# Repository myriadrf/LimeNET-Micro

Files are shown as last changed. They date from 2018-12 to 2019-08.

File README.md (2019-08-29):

# LimeNET-Micro

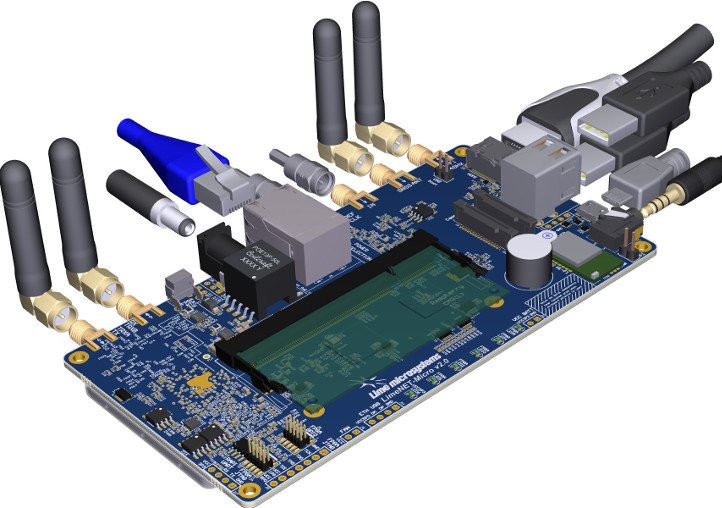
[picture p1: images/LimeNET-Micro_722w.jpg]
LimeNET-Micro board


The [LimeNET Micro](https://www.crowdsupply.com/lime-micro/limenet-micro) makes deploying wireless networks more accessible than ever before, by extending the LimeNET line of integrated hardware solutions via an ultra-low cost platform that is capable of supporting narrowband systems, such as GSM and IoT wireless standards, in a stand-alone configuration.

* **RF transceiver:** Lime Microsystems LMS7002M
* **FPGA Features** 
  * Intel Altera MAX 10 (10M16SAU169C8G)
  * 169-pin FBGA package
  * 16K LEs
  * 549 KB M9K memory
  * 2,368 KB user flash memory
  * 4 x fractional phase locked loops (PLLs)
  * 45 x 18x18-bit multipliers
  * 130 x general purpose input/output (GPIO)
  * Single supply voltage
  * Flash feature
  * FPGA configuration via JTAG
* **GNSS module:** u-blox NEO-M8Q-0-10
  * Supports BeiDou, Galileo, GLONASS, GPS / QZSS
  * Able to concurrently receive up to three GNSS
  * –167 dBm navigation sensitivity
* **EEPROM memory:** 2 x 128 KB for RF transceiver MCU firmware and data
* **Flash memory:** 1 x 4 MB flash memory for data
* **General user inputs/outputs:**
  * 5 x dual color (red + green) LED
  * 8 x FPGA GPIO pinheader (3.3 V)
  * 4 x FPGA switches
  * 1 x buzzer
* **Connectivity:**
  * 2 x coaxial RF (SMA) connectors (each can be switched between high and low frequency bands)
  * SMA connector for external clock source in
  * SMA connector for clock source out
  * SMA connector for GNSS antenna
  * Raspberry Pi Touch Screen Display Connector (ribbon cable)
  * Raspberry Pi Camera (ribbon cable)
  * HDMI connector
  * 2 x USB 2.0 ports
  * 3.5 mm audio out (Raspberry Pi Compute Module)
  * FPGA GPIO headers
  * FPGA JTAG connector
  * RJ45 connector for Ethernet and IEEE 802.3 active Power-over-Ethernet (PoE)
  * DDR2 SODIMM connector - only usable for Raspberry Pi Compute Module 3 (or Lite)
  * MicroSD slot for RPi Compute Module storage
  * Barrel connector for 5 V DC power
  * Micro-USB for USB boot of Compute Module
* **Clock system:**
  * 30.72 MHz OCXO: Rakon U7475LF
  * GPS disciplined for high frequency accuracy and stability
  * External clock input via SMA connector
  * Clock output via SMA connector
* **Board dimensions:** 125 mm x 65 mm

## Contents

The directory structure is as follows:

      hardware/<version>/
          Libraries/             - Component Libraries
          OutputJobs/            - Output jobs
          PCB/                   - PCB design
          Project Outputs/       - BOM, rule check reports, Gerbers, pick & place files, PDFs
          Schematics/            - Schematic diagrams

## Licensing

The hardware designs are licensed under a Creative Commons Attribution 3.0 Unported licence.

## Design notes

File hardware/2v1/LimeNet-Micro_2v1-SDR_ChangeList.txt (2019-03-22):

Changes:

LimeNet-Micro_2v1-SDR(_DB)_DFMr0:
 - Initial version

LimeNet-Micro_2v1-SDR(_DB)_DFMr1:
 - R77 changed from 10k to 22R (made same as ex. R135);
 - R114 made NF;
 - J26 made FIT;
 - New schematic and BOM (revision r1) generated.
 
LimeNet-Micro_2v1-SDR(_DB)_DFMr2:
 - R107 changed from 10k to 22R (made same as ex. R135);
 - New schematic and BOM (revision r2) generated.

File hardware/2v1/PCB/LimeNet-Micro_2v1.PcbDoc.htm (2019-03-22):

Reporting Options

# File in Previous Format

Date | : | 2019-02-14
Time | : | 10:52:01
Filename | : | d:\Lime\LimePCBs\LimeNET-Micro_2v1\History\SDR_FOR_CROWD\LimeNET-Micro_2v1-SDR_r01\PCB\LimeNet-Micro_2v1.PcbDoc

Version | Warning

This file was generated by an earlier version of the software

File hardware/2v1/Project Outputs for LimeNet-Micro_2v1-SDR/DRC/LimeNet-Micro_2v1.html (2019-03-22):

Altium

# Design Rule Verification Report

Date: | | 2019-01-22
Time: | | 12:07:39
Elapsed Time: | | 00:00:58
Filename: | | d:\Lime\LimePCBs\LimeNET-Micro_2v1\Altium Designer design files\PCB\LimeNet-Micro_2v1.PcbDoc

Warnings: | | 0
Rule Violations: | | 0

## Summary

Warnings | Count
Total | 0

Rule Violations | Count
Clearance Constraint (Gap=0.1mm) (All),(All) | 0
Short-Circuit Constraint (Allowed=No) (All),(All) | 0
Un-Routed Net Constraint ( (All) ) | 0
Modified Polygon (Allow modified: No), (Allow shelved: No) | 0
Width Constraint (Min=0.1mm) (Max=7mm) (Preferred=0.2mm) (All) | 0
Width Constraint (Min=0.1mm) (Max=5mm) (Preferred=0.2mm) (All) | 0
Routing Layers(All) | 0
Routing Via (MinHoleWidth=0.2mm) (MaxHoleWidth=4.5mm) (PreferredHoleWidth=0.2mm) (MinWidth=0.31mm) (MaxWidth=5mm) (PreferedWidth=0.4mm) (All) | 0
Differential Pairs Uncoupled Length using the Gap Constraints (Min=0.1mm) (Max=0.3mm) (Prefered=0.14mm) and Width Constraints (Min=0.2mm) (Max=0.2mm) (Prefered=0.2mm) (InNetClass('RAPI_HDMI')) | 0
Differential Pairs Uncoupled Length using the Gap Constraints (Min=0.1mm) (Max=0.3mm) (Prefered=0.1mm) and Width Constraints (Min=0.1mm) (Max=0.5mm) (Prefered=0.2mm) (All) | 0
Differential Pairs Uncoupled Length using the Gap Constraints (Min=0.1mm) (Max=0.3mm) (Prefered=0.14mm) and Width Constraints (Min=0.1mm) (Max=0.3mm) (Prefered=0.2mm) (InNetClass('TX_RF')) | 0
Differential Pairs Uncoupled Length using the Gap Constraints (Min=0.1mm) (Max=0.3mm) (Prefered=0.14mm) and Width Constraints (Min=0.1mm) (Max=0.3mm) (Prefered=0.2mm) (InNetClass('RX_RF')) | 0
Power Plane Connect Rule(Relief Connect )(Expansion=0.508mm) (Conductor Width=0.254mm) (Air Gap=0.254mm) (Entries=4) (All) | 0
Hole Size Constraint (Min=0.2mm) (Max=10mm) (All) | 0
Pads and Vias to follow the Drill pairs settings | 0
Hole To Hole Clearance (Gap=0.15mm) (All),(All) | 0
Minimum Solder Mask Sliver (Gap=0.099mm) (All),(All) | 0
Net Antennae (Tolerance=0mm) (All) | 0
Matched Lengths(Tolerance=1mm) (InNetClass('LMS_PORT1')) | 0
Matched Lengths(Tolerance=10mm) (InNetClass('LMS_PORT2')) | 0
Matched Lengths(Tolerance=1.6mm) (InNetClass('RAPI_SPI0')) | 0
Matched Lengths(Tolerance=1.6mm) (InNetClass('RAPI_SDX')) | 0
Matched Lengths(Tolerance=1.6mm) (InNetClass('RAPI_SPI1')) | 0
Matched Lengths(Tolerance=1.6mm) (InNetClass('FT_FIFO')) | 0
Component Clearance Constraint ( Horizontal Gap = -1mm, Vertical Gap = Infinite ) (InComponent('R171') or InComponent('R162') or InComponent('R174')),(InComponent('R171') or InComponent('R162') or InComponent('R174')) | 0
Component Clearance Constraint ( Horizontal Gap = -1mm, Vertical Gap = Infinite ) (InComponent('IC2')),(InComponent('IC3')) | 0
Component Clearance Constraint ( Horizontal Gap = -1mm, Vertical Gap = Infinite ) (InComponent('IC16')),(InComponent('IC18')) | 0
Component Clearance Constraint ( Horizontal Gap = -1mm, Vertical Gap = Infinite ) (HasFootprint('RFI_SHIELD_BMI-S-230-F-R')),(All) | 0
Component Clearance Constraint ( Horizontal Gap = 0.01mm, Vertical Gap = 0.254mm ) (All),(All) | 0
Component Clearance Constraint ( Horizontal Gap = -1mm, Vertical Gap = Infinite ) (InComponent('IC21')),(InComponent('IC20')) | 0
Component Clearance Constraint ( Horizontal Gap = -1mm, Vertical Gap = Infinite ) (InComponent('J27')),(InComponent('J28')) | 0
Component Clearance Constraint ( Horizontal Gap = -1mm, Vertical Gap = Infinite ) (HasFootprint('SW_4WAY_SMD_1P27_v2')),(All) | 0
Component Clearance Constraint ( Horizontal Gap = -1mm, Vertical Gap = Infinite ) (InComponent('IC12')),(InComponent('IC14')) | 0
Height Constraint (Min=0mm) (Max=25.4mm) (Prefered=12.7mm) (All) | 0
Total | 0

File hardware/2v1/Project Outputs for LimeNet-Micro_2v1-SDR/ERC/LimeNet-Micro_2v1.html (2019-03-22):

Altium

# Electrical Rule Check Report

Date: | | 2019-01-22
Time: | | 12:08:42
Filename: | | d:\Lime\LimePCBs\LimeNET-Micro_2v1\Altium Designer design files\Project Outputs for LimeNet-Micro_2v1\ERC\LimeNet-Micro_2v1.html

Class | Document | Message
Warning | LimeNet-Micro_2v1.PcbDoc | Component BR1 at 51.775mm,80.7mm: Can't perform revision status validation: Failed to connect to vault.
Warning | 15_PowerSupply.SchDoc | GND contains IO Pin and Output Pin objects (Pin IC12-F4,Pin IC46-PAD,Pin IC45-PAD,Pin IC40-PAD,Pin IC39-PAD)
Warning | 15_PowerSupply.SchDoc | GND contains IO Pin and Power Pin objects (Pin LED6-3,Pin IC16-4,Pin IC2-4,Pin IC37-5,Pin IC12-F4,Pin IC16-PAD,Pin IC2-PAD)
Warning | 10_USB_Ethernet.SchDoc | Net ETH_CLK24_EN has no driving source (Pin IC24-44,Pin R92-2,Pin R95-1)
Warning | 10_USB_Ethernet.SchDoc | Net ETH_USB_VBUS has no driving source (Pin IC24-11,Pin R80-2)
Warning | 13_Raspberry_Misc.SchDoc | Net EXT_USB_CTRL has no driving source (Pin IC29-10,Pin IC31-10,Pin J18-1,Pin R143-1,Pin R145-1)
Warning | 14_Clocks.SchDoc | Net FPGA_SPI_DAC_SS_R has no driving source (Pin IC35-5,Pin IC37-1,Pin R196-1)
Warning | 14_Clocks.SchDoc | Net FPGA_SPI_MOSI_R has no driving source (Pin IC35-7,Pin IC37-3,Pin R198-1)
Warning | 14_Clocks.SchDoc | Net FPGA_SPI_SCLK_R has no driving source (Pin IC35-6,Pin IC37-2,Pin R197-1)
Warning | 15_PowerSupply.SchDoc | Net GND contains multiple Output Pins (Pin IC46-PAD,Pin IC45-PAD,Pin IC40-PAD,Pin IC39-PAD)
Warning | 05_LMS7002M_Misc.SchDoc | Net LMS_I2C_SCL has no driving source (Pin IC1-C27,Pin IC2-6,Pin IC3-6,Pin R13-2)
Warning | 10_USB_Ethernet.SchDoc | Net NetC167_2 has no driving source (Pin C167-2,Pin IC24-61,Pin R86-1,Pin XT1-1)
Warning | 14_Clocks.SchDoc | Net NetC259_2 has no driving source (Pin C259-2,Pin XO4-7)
Warning | 15_PowerSupply.SchDoc | Net NetC312_2 has no driving source (Pin C312-2,Pin FR50-2,Pin IC41-5,Pin IC41-8)
Warning | 15_PowerSupply.SchDoc | Net NetC314_2 has no driving source (Pin C314-2,Pin FR51-2,Pin IC42-5,Pin IC42-8)
Warning | 15_PowerSupply.SchDoc | Net NetC316_1 has no driving source (Pin C316-1,Pin IC39-2,Pin R221-1,Pin R225-2)
Warning | 15_PowerSupply.SchDoc | Net NetC317_1 has no driving source (Pin C317-1,Pin IC40-2,Pin R222-1,Pin R226-2)
Warning | 15_PowerSupply.SchDoc | Net NetC318_2 has no driving source (Pin C318-2,Pin FR52-2,Pin IC43-5,Pin IC43-8)
Warning | 15_PowerSupply.SchDoc | Net NetC320_2 has no driving source (Pin C320-2,Pin FR53-2,Pin IC44-5,Pin IC44-8)
Warning | 15_PowerSupply.SchDoc | Net NetC327_1 has no driving source (Pin C327-1,Pin IC45-2,Pin R233-1,Pin R236-2)
Warning | 15_PowerSupply.SchDoc | Net NetC328_1 has no driving source (Pin C328-1,Pin IC46-2,Pin R234-1,Pin R237-2)
Warning | 08_FPGA.SchDoc | Net NetIC12_E7 has no driving source (Pin IC12-E7,Pin R40-2)
Warning | 10_USB_Ethernet.SchDoc | Net NetIC24_50 has no driving source (Pin IC24-50,Pin R94-1)
Warning | 10_USB_Ethernet.SchDoc | Net NetIC24_63 has no driving source (Pin IC24-63,Pin R93-1)
Warning | 10_USB_Ethernet.SchDoc | Net NetIC26_5 has no driving source (Pin IC26-5,Pin R100-1,Pin R101-1)
Warning | 13_Raspberry_Misc.SchDoc | Net NetIC28_10 has no driving source (Pin IC28-10,Pin R138-2,Pin VT5-D)
Warning | 13_Raspberry_Misc.SchDoc | Net NetIC30_9 has no driving source (Pin IC30-9,Pin R144-2)
Warning | 13_Raspberry_Misc.SchDoc | Net NetIC30_23 has no driving source (Pin IC30-23,Pin R147-2,Pin R148-2)
Warning | 13_Raspberry_Misc.SchDoc | Net NetIC30_25 has no driving source (Pin IC30-25,Pin R146-2,Pin R148-1,Pin R149-2)
Warning | 13_Raspberry_Misc.SchDoc | Net NetIC33_5 has no driving source (Pin IC33-5,Pin R160-1)
Warning | 15_PowerSupply.SchDoc | Net NetIC38_12 has no driving source (Pin IC38-12,Pin R209-2)
Warning | 15_PowerSupply.SchDoc | Net NetIC45_1 has no driving source (Pin IC45-1,Pin R229-2)
Warning | 15_PowerSupply.SchDoc | Net NetIC46_1 has no driving source (Pin IC46-1,Pin R230-2)
Warning | 15_PowerSupply.SchDoc | Net POE_CS has no driving source (Pin C307-1,Pin IC38-3,Pin R217-1)
Warning | 15_PowerSupply.SchDoc | Net POE_CTL has no driving source (Pin AT1-4,Pin C304-1,Pin IC38-1,Pin R213-2)
Warning | 13_Raspberry_Misc.SchDoc | Net RAPI_PWM0 has no driving source (Pin IC32-1,Pin J13-70)
Warning | 13_Raspberry_Misc.SchDoc | Net RAPI_PWM1 has no driving source (Pin IC32-3,Pin J13-72)
Warning | 12_Raspbbery CM3.SchDoc | Net RAPI_SD1_CLK has no driving source (Pin IC30-6,Pin R112-2)
Warning | 13_Raspberry_Misc.SchDoc | Net RAPI_SD1_CMD has no driving source (Pin IC30-7,Pin J13-54)
Warning | 14_Clocks.SchDoc | Net TCXO_DAC_VREF has no driving source (Pin C281-2,Pin C282-1,Pin IC35-2,Pin R185-1,Pin R186-1,Pin R187-1)
Warning | 15_PowerSupply.SchDoc | Net VCC5P0 has no driving source (Pin C175-2,Pin C177-1,Pin C231-2,Pin C233-1,Pin C308-2,Pin C310-2,Pin C322-2,Pin C323-2,Pin FR50-1,Pin FR52-1,Pin IC26-1,Pin IC26-3,Pin IC33-1,Pin IC33-3,Pin IC39-7,Pin IC40-7,Pin IC45-7,Pin IC46-7,Pin J3-7,Pin J26-2,Pin J27-2,Pin J27-4,Pin J27-6,Pin R33-1,Pin R61-1,Pin R98-2,Pin R99-1,Pin R103-2,Pin R120-2,Pin R158-2,Pin R159-1,Pin VD4-K)
Warning | 14_Clocks.SchDoc | Net XO_VC has no driving source (Pin R180-1,Pin R184-2,Pin XO1-1,Pin XO2-1,Pin XO3-1,Pin XO4-1)

Back to top

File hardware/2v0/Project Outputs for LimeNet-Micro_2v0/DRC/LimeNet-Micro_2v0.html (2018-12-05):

Altium

# Design Rule Verification Report

Date: | | 2018-11-13
Time: | | 16:06:43
Elapsed Time: | | 00:00:59
Filename: | | d:\Lime\LimePCBs\LimeNET-Micro_2v0\Altium Designer design files\PCB\LimeNet-Micro_2v0.PcbDoc

Warnings: | | 0
Rule Violations: | | 0

## Summary

Warnings | Count
Total | 0

Rule Violations | Count
Clearance Constraint (Gap=0.1mm) (All),(All) | 0
Short-Circuit Constraint (Allowed=No) (All),(All) | 0
Un-Routed Net Constraint ( (All) ) | 0
Modified Polygon (Allow modified: No), (Allow shelved: No) | 0
Width Constraint (Min=0.1mm) (Max=7mm) (Preferred=0.2mm) (All) | 0
Width Constraint (Min=0.1mm) (Max=5mm) (Preferred=0.2mm) (All) | 0
Routing Layers(All) | 0
Routing Via (MinHoleWidth=0.2mm) (MaxHoleWidth=4.5mm) (PreferredHoleWidth=0.2mm) (MinWidth=0.31mm) (MaxWidth=5mm) (PreferedWidth=0.4mm) (All) | 0
Differential Pairs Uncoupled Length using the Gap Constraints (Min=0.1mm) (Max=0.3mm) (Prefered=0.14mm) and Width Constraints (Min=0.2mm) (Max=0.2mm) (Prefered=0.2mm) (InNetClass('RAPI_HDMI')) | 0
Differential Pairs Uncoupled Length using the Gap Constraints (Min=0.1mm) (Max=0.3mm) (Prefered=0.1mm) and Width Constraints (Min=0.1mm) (Max=0.5mm) (Prefered=0.2mm) (All) | 0
Differential Pairs Uncoupled Length using the Gap Constraints (Min=0.1mm) (Max=0.3mm) (Prefered=0.14mm) and Width Constraints (Min=0.1mm) (Max=0.3mm) (Prefered=0.2mm) (InNetClass('TX_RF')) | 0
Differential Pairs Uncoupled Length using the Gap Constraints (Min=0.1mm) (Max=0.3mm) (Prefered=0.14mm) and Width Constraints (Min=0.1mm) (Max=0.3mm) (Prefered=0.2mm) (InNetClass('RX_RF')) | 0
Power Plane Connect Rule(Relief Connect )(Expansion=0.508mm) (Conductor Width=0.254mm) (Air Gap=0.254mm) (Entries=4) (All) | 0
Hole Size Constraint (Min=0.2mm) (Max=10mm) (All) | 0
Pads and Vias to follow the Drill pairs settings | 0
Hole To Hole Clearance (Gap=0.15mm) (All),(All) | 0
Minimum Solder Mask Sliver (Gap=0.099mm) (All),(All) | 0
Net Antennae (Tolerance=0mm) (All) | 0
Matched Lengths(Tolerance=1mm) (InNetClass('LMS_PORT1')) | 0
Matched Lengths(Tolerance=1mm) (InNetClass('LMS_PORT2')) | 0
Matched Lengths(Tolerance=1.6mm) (InNetClass('FT_FIFO')) | 0
Matched Lengths(Tolerance=1.6mm) (InNetClass('RAPI_SDX')) | 0
Matched Lengths(Tolerance=1.6mm) (InNetClass('RAPI_SPI1')) | 0
Matched Lengths(Tolerance=1.6mm) (InNetClass('RAPI_SPI0')) | 0
Component Clearance Constraint ( Horizontal Gap = -1mm, Vertical Gap = Infinite ) (InComponent('R171') or InComponent('R180') or InComponent('R183')),(InComponent('R171') or InComponent('R180') or InComponent('R183')) | 0
Component Clearance Constraint ( Horizontal Gap = -1mm, Vertical Gap = Infinite ) (InComponent('R16') or InComponent('R18') or InComponent('R14') or InComponent('R15') or InComponent('R19') or InComponent('R20') or InComponent('R22') or InComponent('R23')),(InComponent('R16') or InComponent('R18') or InComponent('R14') or InComponent('R15') or InComponent('R19') or InComponent('R20') or InComponent('R22') or InComponent('R23')) | 0
Component Clearance Constraint ( Horizontal Gap = -1mm, Vertical Gap = Infinite ) (InComponent('IC2')),(InComponent('IC3')) | 0
Component Clearance Constraint ( Horizontal Gap = -1mm, Vertical Gap = Infinite ) (InComponent('IC9')),(InComponent('IC10')) | 0
Component Clearance Constraint ( Horizontal Gap = -1mm, Vertical Gap = Infinite ) (HasFootprint('RFI_SHIELD_BMI-S-230-F-R')),(All) | 0
Component Clearance Constraint ( Horizontal Gap = 0.01mm, Vertical Gap = 0.254mm ) (All),(All) | 0
Component Clearance Constraint ( Horizontal Gap = -1mm, Vertical Gap = Infinite ) (InComponent('IC16')),(InComponent('IC17')) | 0
Component Clearance Constraint ( Horizontal Gap = -1mm, Vertical Gap = Infinite ) (InComponent('J27')),(InComponent('J28')) | 0
Component Clearance Constraint ( Horizontal Gap = -1mm, Vertical Gap = Infinite ) (HasFootprint('SW_4WAY_SMD_1P27_v2')),(All) | 0
Component Clearance Constraint ( Horizontal Gap = -1mm, Vertical Gap = Infinite ) (InComponent('IC12')),(InComponent('IC14')) | 0
Height Constraint (Min=0mm) (Max=25.4mm) (Prefered=12.7mm) (All) | 0
Total | 0

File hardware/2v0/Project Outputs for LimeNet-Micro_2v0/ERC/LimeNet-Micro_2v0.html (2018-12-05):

Altium

# Electrical Rule Check Report

Date: | | 2018-11-13
Time: | | 16:07:45
Filename: | | d:\Lime\LimePCBs\LimeNET-Micro_2v0\Altium Designer design files\Project Outputs for LimeNet-Micro_2v0\ERC\LimeNet-Micro_2v0.html

Class | Document | Message
Warning | 15_PowerSupply.SchDoc | GND contains IO Pin and Output Pin objects (Pin IC8-E3,Pin IC8-F4,Pin IC41-PAD,Pin IC36-PAD,Pin IC35-PAD)
Warning | 15_PowerSupply.SchDoc | GND contains IO Pin and Power Pin objects (Pin LED6-3,Pin IC12-4,Pin IC2-4,Pin IC33-5,Pin IC8-E3,Pin IC8-F4,Pin IC12-PAD,Pin IC2-PAD)
Warning | 10_USB_Ethernet.SchDoc | Net ETH_CLK24_EN has no driving source (Pin IC20-44,Pin R104-2,Pin R107-1)
Warning | 10_USB_Ethernet.SchDoc | Net ETH_USB_VBUS has no driving source (Pin IC20-11,Pin R90-2)
Warning | 13_Raspberry_Misc.SchDoc | Net EXT_USB_CTRL has no driving source (Pin IC25-10,Pin IC27-10,Pin J18-1,Pin R153-1,Pin R155-1)
Warning | 14_Clocks.SchDoc | Net FPGA_SPI_DAC_SS_R has no driving source (Pin IC31-5,Pin IC33-1,Pin R205-1)
Warning | 14_Clocks.SchDoc | Net FPGA_SPI_MOSI_R has no driving source (Pin IC31-7,Pin IC33-3,Pin R207-1)
Warning | 14_Clocks.SchDoc | Net FPGA_SPI_SCLK_R has no driving source (Pin IC31-6,Pin IC33-2,Pin R206-1)
Warning | 15_PowerSupply.SchDoc | Net GND contains multiple Output Pins (Pin IC41-PAD,Pin IC36-PAD,Pin IC35-PAD)
Warning | 05_LMS7002M_Misc.SchDoc | Net LMS_I2C_SCL has no driving source (Pin IC1-C27,Pin IC2-6,Pin IC3-6,Pin R13-2)
Warning | 14_Clocks.SchDoc | Net NetC244_2 has no driving source (Pin C244-2,Pin XO4-7)
Warning | 15_PowerSupply.SchDoc | Net NetC302_2 has no driving source (Pin C302-2,Pin FR47-2,Pin IC37-5,Pin IC37-8)
Warning | 15_PowerSupply.SchDoc | Net NetC304_2 has no driving source (Pin C304-2,Pin FR48-2,Pin IC38-5,Pin IC38-8)
Warning | 15_PowerSupply.SchDoc | Net NetC306_1 has no driving source (Pin C306-1,Pin IC35-2,Pin R237-1,Pin R241-2)
Warning | 15_PowerSupply.SchDoc | Net NetC307_1 has no driving source (Pin C307-1,Pin IC36-2,Pin R238-1,Pin R242-2)
Warning | 15_PowerSupply.SchDoc | Net NetC308_2 has no driving source (Pin C308-2,Pin FR49-2,Pin IC39-5,Pin IC39-8)
Warning | 15_PowerSupply.SchDoc | Net NetC310_2 has no driving source (Pin C310-2,Pin FR50-2,Pin IC40-5,Pin IC40-8)
Warning | 15_PowerSupply.SchDoc | Net NetC315_1 has no driving source (Pin C315-1,Pin IC41-2,Pin R248-1,Pin R249-2)
Warning | 08_FPGA.SchDoc | Net NetIC8_E7 has no driving source (Pin IC8-E7,Pin R50-2)
Warning | 10_USB_Ethernet.SchDoc | Net NetIC20_50 has no driving source (Pin IC20-50,Pin R106-1)
Warning | 10_USB_Ethernet.SchDoc | Net NetIC20_61 has no driving source (Pin IC20-61,Pin R95-1,Pin R96-1)
Warning | 10_USB_Ethernet.SchDoc | Net NetIC20_63 has no driving source (Pin IC20-63,Pin R105-1)
Warning | 10_USB_Ethernet.SchDoc | Net NetIC22_5 has no driving source (Pin IC22-5,Pin R111-1,Pin R112-1)
Warning | 13_Raspberry_Misc.SchDoc | Net NetIC24_10 has no driving source (Pin IC24-10,Pin R147-2,Pin VT5-D)
Warning | 13_Raspberry_Misc.SchDoc | Net NetIC26_9 has no driving source (Pin IC26-9,Pin R154-1)
Warning | 13_Raspberry_Misc.SchDoc | Net NetIC26_23 has no driving source (Pin IC26-23,Pin R157-2,Pin R158-2)
Warning | 13_Raspberry_Misc.SchDoc | Net NetIC26_25 has no driving source (Pin IC26-25,Pin R156-2,Pin R158-1,Pin R159-2)
Warning | 13_Raspberry_Misc.SchDoc | Net NetIC29_5 has no driving source (Pin IC29-5,Pin R169-1)
Warning | 15_PowerSupply.SchDoc | Net NetIC41_1 has no driving source (Pin IC41-1,Pin R245-2)
Warning | 13_Raspberry_Misc.SchDoc | Net RAPI_PWM0 has no driving source (Pin IC28-3,Pin J13-70)
Warning | 13_Raspberry_Misc.SchDoc | Net RAPI_PWM1 has no driving source (Pin IC28-1,Pin J13-72)
Warning | 12_Raspbbery CM3.SchDoc | Net RAPI_SD1_CLK has no driving source (Pin IC26-6,Pin R252-2)
Warning | 13_Raspberry_Misc.SchDoc | Net RAPI_SD1_CMD has no driving source (Pin IC26-7,Pin J13-54)
Warning | 14_Clocks.SchDoc | Net TCXO_DAC_VREF has no driving source (Pin C266-2,Pin C267-1,Pin IC31-2,Pin R194-1,Pin R195-1,Pin R196-1)
Warning | 15_PowerSupply.SchDoc | Net VCC5P0 has no driving source (Pin C161-2,Pin C163-1,Pin C216-2,Pin C218-1,Pin C298-2,Pin C300-2,Pin C312-2,Pin FR47-1,Pin FR49-1,Pin IC22-1,Pin IC22-3,Pin IC29-1,Pin IC29-3,Pin IC35-7,Pin IC36-7,Pin IC41-7,Pin J3-7,Pin J27-2,Pin J28-2,Pin R43-1,Pin R71-1,Pin R110-1,Pin R114-2,Pin R130-2,Pin R168-1,Pin R224-1,Pin VD7-K)
Warning | 14_Clocks.SchDoc | Net XO_VC has no driving source (Pin R189-1,Pin R193-2,Pin XO1-1,Pin XO2-1,Pin XO3-1,Pin XO4-1)

Back to top

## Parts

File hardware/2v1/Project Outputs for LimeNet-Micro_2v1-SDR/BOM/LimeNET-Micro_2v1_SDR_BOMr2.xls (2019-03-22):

Item # | Comment | Quantity | Designator | Footprint | Manufacturer | Manufacturer Part Number 1 | Supplier 1 | Supplier Part Number 1 | Part Description | Assembly Info
1 | TCMT1107CT | 1 | AT1 | TCMT1107CT_optoisolator | Vishay Semiconductors | TCMT1107 | Digi-Key | TCMT1107CT-ND | Optoisolator Transistor Output 5000Vrms 1 Channel 4-SMD
2 | HD01-T | 2 | BR1, BR2 | HD01-T _RECTIFIER_BRIDGE_v1 | Diodes | HD01-T | Digi-Key | HD01DITR-ND | Bridge Rectifier Single Phase Standard 100V Surface Mount 4-MiniDIP
3 | 10pF, 25V | 8 | C1, C20, C21, C30, C31, C167, C168, C283 | CAP0402 | AVX | 04023A100JAT2A | Farnell | 2332478RL | 10pF ±5% 25V C0G, NP0 Ceramic Capacitor -55°C ~ 125°C Surface Mount, MLCC 0402 (1005 Metric) 0.039" L x 0.020" W (1.00mm x 0.50mm)
4 | 100nF, 16V | 73 | C2, C4, C6, C14, C17, C98, C135, C137, C138, C139, C141, C142, C143, C144, C145, C146, C147, C148, C149, C151, C153, C155, C156, C157, C158, C159, C160, C161, C162, C163, C164, C165, C166, C169, C177, C178, C179, C181, C202, C212, C214, C215, C217, C218, C219, C220, C221, C222, C223, C226, C227, C230, C233, C234, C235, C236, C237, C240, C244, C249, C252, C255, C258, C260, C261, C267, C272, C273, C282, C284, C330, MN15, MN20 | CAP0402 | Murata Electronics | GRM155R71C104KA88D | Mouser | 81-GRM155R71C104KA88 | CAP CER 0.1UF 16V X7R 0402 | NF(C135 C169 C179 C218 C220 C221 C222 C223 C255 C258 C272 C284)
5 | 100pF, 50V | 47 | C3, C5, C7, C8, C9, C10, C11, C12, C13, C15, C16, C18, C19, C22, C23, C24, C25, C26, C27, C28, C29, C32, C33, C34, C35, C36, C37, C38, C134, C136, C140, C239, C245, C246, C250, C251, C253, C254, C262, C263, C264, C265, C268, C269, C270, C271, C300 | CAP0402 | Yageo | CC0402JRNPO9BN101 | Digi-Key | 311-1024-1-ND | 100pF ±5% 50V C0G, NP0 Ceramic Capacitor -55°C ~ 125°C Surface Mount, MLCC 0402 (1005 Metric) 0.039" L x 0.020" W (1.00mm x 0.50mm) | NF(C7 C8 C18 C19 C24 C32)
6 | 1uF, 6.3V | 60 | C39, C42, C44, C46, C48, C50, C51, C52, C53, C54, C55, C56, C57, C58, C59, C60, C61, C62, C63, C65, C66, C67, C68, C69, C70, C72, C74, C76, C77, C78, C79, C80, C81, C82, C83, C84, C85, C86, C87, C88, C89, C90, C91, C92, C93, C94, C95, C96, C97, C100, C107, C114, C120, C124, C184, C186, C188, C190, C193, C201 | CAP0201 | TDK Corporation | JMK063ABJ105MP-F | Digi-Key | 587-5864-2-ND | 1µF ±20% 6.3V X5R Ceramic Capacitor -55°C ~ 85°C Surface Mount, MLCC 0201 (0603 Metric) 0.024" L x 0.012" W (0.60mm x 0.30mm)
7 | 10uF, 6.3V | 12 | C40, C99, C106, C113, C119, C123, C133, C183, C192, C200, C213, C325 | CAP0603 | Yageo | CC0603MRX5R5BB106 | Digi-Key | 311-1448-2-ND | 10µF ±20% 6.3V X5R Ceramic Capacitor -55°C ~ 85°C Surface Mount, MLCC 0603 (1608 Metric) 0.063" L x 0.031" W (1.60mm x 0.80mm)
8 | 1nF, 10% | 9 | C41, C43, C45, C47, C49, C64, C71, C73, C75 | CAP0201 | TDK Corporation | C0603X7R1E102K030BA | Digi-Key | 445-7275-1-ND | 1000pF ±10% 25V X7R Ceramic Capacitor -55°C ~ 125°C Surface Mount, MLCC 0201 (0603 Metric) 0.024" L x 0.012" W (0.60mm x 0.30mm)
9 | 100nF, 6.3V | 30 | C101, C102, C103, C104, C105, C108, C109, C110, C111, C112, C115, C116, C117, C118, C121, C122, C125, C126, C127, C128, C129, C130, C131, C185, C187, C189, C191, C194, C196, C198 | CAP0201 | Murata | GRT033C81A104KE01D | Digi-Key | 490-12232-1-ND | 0.10µF ±10% 6.3V X6S Ceramic Capacitor -55°C ~ 105°C Surface Mount, MLCC 0201 (0603 Metric) 0.024" L x 0.012" W (0.60mm x 0.30mm)
10 | 1uF, 10V | 17 | C132, C154, C204, C205, C206, C207, C229, C243, C247, C248, C256, C257, C266, C281, C292, C305, C329 | CAP0402 | Yageo | CC0402MRX5R6BB105 | Digi-Key | 311-1732-1-ND | 1µF 10V Ceramic Capacitor X5R 0402 (1005 Metric) 0.039" L x 0.020" W (1.00mm x 0.50mm) | NF(C256 C257)
11 | 4.7uF, 6.3V | 11 | C150, C203, C211, C312, C313, C314, C315, C318, C319, C320, C321 | CAP0402 | Murata Electronics North America | GRM155R60J475ME87D | Digi-Key | 490-5408-1-ND | 4.7µF ±20% 6.3V X5R Ceramic Capacitor -55°C ~ 85°C Surface Mount, MLCC 0402 (1005 Metric) 0.039" L x 0.020" W (1.00mm x 0.50mm) | NF(C312 C313)
12 | 22nF, 50V | 1 | C152 | CAP0402 | Kemet | C0402C223K5RACTU | Digi-Key | 399-7780-1-ND | 0.022µF ±10% 50V Ceramic Capacitor X7R 0402 (1005 Metric)
13 | 13pF, 5% | 4 | C170, C171, C172, C173 | CAP0402 | Murata Electronics North America | GRM1555C1H130JA01D | Digi-Key | 490-5925-2-ND | 13pF ±5% 50V C0G, NP0 Ceramic Capacitor -55°C ~ 125°C Surface Mount, MLCC 0402 (1005 Metric) 0.039" L x 0.020" W (1.00mm x 0.50mm)
14 | 47uF, 10V | 6 | C174, C208, C209, C210, C225, C228 | CAP1206 | TDK Corporation | C3216X6S1A476M160AC | Digi-Key | 445-6010-1-ND | 47µF ±20% 10V Ceramic Capacitor X6S 1206 (3216 Metric)
15 | 22uF, 10V | 13 | C175, C176, C224, C231, C232, C308, C309, C310, C311, C322, C323, C324, C326 | CAP0603 | TDK Corporation | C1608X5R1A226M080AC | Mouser | 810-C1608X5R1A226M | 22µF ±20% 10V X5R Ceramic Capacitor -55°C ~ 85°C Surface Mount, MLCC 0603 (1608 Metric) 0.063" L x 0.031" W (1.60mm x 0.80mm) | NF(C224)
16 | 10pF, 5% | 2 | C180, C182 | CAP0402 | AVX | 04023A100JAT2A | Farnell | 2332478RL | 10pF ±5% 25V C0G, NP0 Ceramic Capacitor -55°C ~ 125°C Surface Mount, MLCC 0402 (1005 Metric) 0.039" L x 0.020" W (1.00mm x 0.50mm)
17 | 10nF, 50V | 3 | C195, C197, C199 | CAP0402 | Murata Electronics North America | GRM155R71H103KA88D | Digi-Key | 490-4516-2-ND | 10000pF ±10% 50V Ceramic Capacitor X7R 0402 (1005 Metric)
18 | 4.7nF, 50V | 1 | C216 | CAP0402 | Murata Electronics North America | GCM155R71H472KA37D | Digi-Key | 490-4915-1-ND | 4700pF ±10% 50V Ceramic Capacitor X7R 0402 (1005 Metric)
19 | 10uF, 16V | 1 | C238 | CAP0603 | Yageo | GRM188R61C106MA73D | Digi-Key | 490-7201-2-ND | 10µF ±20% 16V Ceramic Capacitor X5R 0603 (1608 Metric)
20 | 47pF, 50V | 2 | C241, C242 | CAP0402 | TDK Corporation | C1005C0G1H470F050BA | Digi-Key | 445-5361-1-ND | 47pF ±1% 50V C0G, NP0 Ceramic Capacitor -55°C ~ 125°C Surface Mount, MLCC 0402 (1005 Metric) 0.039" L x 0.020" W (1.00mm x 0.50mm) | NF(C241 C242)
21 | 18nF, 16V | 1 | C259 | CAP0402 | Yageo | CC0402KRX7R7BB183 | Digi-Key | 311-1706-1-ND | 0.018µF ±10% 16V Ceramic Capacitor X7R 0402 (1005 Metric) | NF(C259)
22 | 1nF, 10% | 2 | C274, C275 | CAP0402 | Murata Electronics | GCM155R71H102KA37D | Mouser | 81-GCM155R71H102KA7D | 1000pF ±10% 50V X7R Ceramic Capacitor -55°C ~ 125°C Surface Mount, MLCC 0402 (1005 Metric) 0.039" L x 0.020" W (1.00mm x 0.50mm)
23 | 1nF, 50V | 1 | C276 | CAP0402 | Murata Electronics North America | GCM155R71H102KA37D | Digi-Key | 490-4761-1-ND | 1000pF ±10% 50V Ceramic Capacitor X7R 0402 (1005 Metric)
24 | 22pF, 5% | 3 | C277, C278, C279 | CAP0402 | Yageo | CC0402JRNPO9BN220 | Digi-Key | 311-1018-2-ND | 22pF ±5% 50V C0G, NP0 Ceramic Capacitor -55°C ~ 125°C Surface Mount, MLCC 0402 (1005 Metric) 0.039" L x 0.020" W (1.00mm x 0.50mm)
25 | 220pF, 10% | 1 | C280 | CAP0402 | Yageo | CC0402KRX7R9BB221 | Digi-Key | 311-1035-2-ND | 220pF ±10% 50V X7R Ceramic Capacitor -55°C ~ 125°C Surface Mount, MLCC 0402 (1005 Metric) 0.039" L x 0.020" W (1.00mm x 0.50mm)
26 | 100nF, 100V | 4 | C285, C293, C298, C299 | CAP0603 | Murata Electronics North America | GRM188R72A104KA35D | Digi-Key | 490-3285-1-ND | 0.1µF ±10% 100V Ceramic Capacitor X7R 0603 (1608 Metric)
27 | 10uF, 100V | 2 | C286, C287 | CAP_POL_SIZE_E | Panasonic | EEE2AA100UP | Digi-Key | PCE3966CT-ND | 10µF 100V Aluminum Electrolytic Capacitors Radial, Can - SMD 2000 Hrs @ 85°C
28 | 2.2uF, 100V | 2 | C288, C289 | CAP1206 | TDK Corporation | C3216X7S2A225K160AE | Digi-Key | 445-8900-1-ND | 2.2µF ±10% 100V Ceramic Capacitor X7S 1206 (3216 Metric)
29 | 1nF, 100V | 3 | C290, C291, C297 | CAP0603 | KEMET | C0603C102K1RACTU | Digi-Key | 399-7831-2-ND | 1000pF ±10% 100V Ceramic Capacitor X7R 0603 (1608 Metric)
30 | 100uF, 6.3V | 3 | C294, C295, C296 | CAP1210 | Murata | GRM32EC70J107ME15L | Digi-Key | 490-10530-1-ND | 100µF ±20% 6.3V Ceramic Capacitor X7S 1210 (3225 Metric)
31 | 1uF, 25V | 1 | C301 | CAP0603 | Samsung Electro-Mechanics | CL10A105KA8NNNC | Digi-Key | 1276-1102-1-ND | 1µF ±10% 25V Ceramic Capacitor X5R 0603 (1608 Metric)
32 | 22uF, 16V | 1 | C302 | CAP_POL_SIZE_B | Panasonic | EEE-FK1C220UR | Digi-Key | PCE3786CT-ND | 22µF 16V Aluminum Electrolytic Capacitors Radial, Can - SMD 2000 Hrs @ 105°C
33 | 6800pF, 50V | 1 | C303 | CAP0402 | Walsin Technologies | 0402B682K500CT | Digi-Key | 1292-1225-1-ND | 6800pF ±10% 50V Ceramic Capacitor X7R 0402 (1005 Metric)
34 | 47nF, 50V | 1 | C304 | CAP0603 | Yageo | CC0603KRX7R9BB473 | Digi-Key | 311-1427-1-ND | 0.047µF ±10% 50V Ceramic Capacitor X7R 0603 (1608 Metric)
35 | 1000pF, 2kV | 1 | C306 | CAP1812 | KEMET | C1812C102KGRACTU | Digi-Key | 399-3447-1-ND | 1000pF ±10% 2000V (2kV) Ceramic Capacitor X7R 1812 (4532 Metric)
36 | 470pF, 50V | 5 | C307, C316, C317, C327, C328 | CAP0402 | TDK Corporation | C1005C0G1H471J050BA | Digi-Key | 445-2656-6-ND | 470pF ±5% 50V Ceramic Capacitor C0G, NP0 0402 (1005 Metric) | NF(C307)
37 | MBR0530 | 1 | D1 | MBR0530T1G_shottky_diode_SOD123 | ON Semiconductor / Fairchild | MBR0530T1G | Digi-Key | MBR0530T1GOSCT-ND | Diode Schottky 30V 500mA Surface Mount SOD-123
38 | MMSZ5245B | 2 | D2, D3 | MMSZ5245B_shottky_diode_SOD123 | Vishay Semiconductors | MMSZ5245B-E3-18 | Digi-Key | MMSZ5245B-E3-18GICT-ND | Zener Diode 15V 500mW ±5% Surface Mount SOD-123
39 | MURA120 | 1 | D4 | MURA120T3G_diode_DO-214AC | ON Semiconductor | MURA120T3G | Digi-Key | MURA120T3GOSCT-ND | Diode Standard 200V 2A Surface Mount SMA
40 | MMSD4148T1G | 1 | D5 | MMSD4148T1G_diode_SOD123 | ON Semiconductor | MMSD4148-T1G | Digi-Key | MMSD4148T1GOSCT-ND | Diode Standard 100V 200mA (DC) Surface Mount SOD-123
41 | BAT54SLT1G | 1 | D6 | BAT54SLT1G_SOT23-3 | ON Semiconductor | BAT54SLT1G | Digi-Key | BAT54SLT1GOSCT-ND | Diode Array 1 Pair Series Connection Schottky 30V 200mA (DC) Surface Mount TO-236-3, SC-59, SOT-23-3
42 | TLV431 | 1 | D7 | SOT23-5 | Texas Instruments | TLV431AIDBVR | Digi-Key | 296-1984-1-ND | Shunt Voltage Reference IC 6V ±1% 15mA SOT-23-5
43 | ESD8472 | 4 | ESD1, ESD2, ESD3, ESD4 | ESD8472_X3DFN2 | ON Semiconductor | ESD8472MUT5G | Digi-Key | ESD8472MUT5GOSCT-ND | TVS DIODE 5.3VWM 14VC X3DFN2 | NF(ESD1 ESD2 ESD3 ESD4)
44 | Fiducial | 8 | F1, F2, F3, F4, F5, F6, F7, F8 | Fiducial
45 | Fiducial | 3 | FL1, FL2, FL3 | Fiducial_local
46 | 600R, 2A | 19 | FR1, FR36, FR37, FR38, FR40, FR41, FR42, FR43, FR44, FR45, FR47, FR48, FR49, FR50, FR51, FR52, FR53, FR54, FR55 | RES0805 | TDK Corporation | MPZ2012S601AT000 | Digi-Key | 445-2206-2-ND | FERRITE BEAD 600 OHM 0805 1LN | NF(FR50)
47 | 600R, 0.27A | 34 | FR2, FR3, FR4, FR5, FR6, FR7, FR8, FR9, FR10, FR11, FR12, FR13, FR14, FR15, FR16, FR17, FR18, FR19, FR20, FR21, FR22, FR23, FR24, FR25, FR26, FR27, FR28, FR29, FR30, FR31, FR32, FR33, FR34, FR46 | RES0201 | Taiyo Yuden | BK0603TS601-T | Digi-Key | 587-3277-1-ND | FERRITE BEAD 600 OHM 0201 1LN
48 | 220R, 0.9A | 2 | FR35, FR39 | RES0402 | TDK Corporation | MPZ1005S221ET000 | Digi-Key | 445-9329-2-ND | FERRITE BEAD 220 OHM 0402 1LN
49 | LMS7002M | 1 | IC1 | LMS7002M_v5 | Lime Microsystems | LMS7002M | Lime Microsystems | LMS7002M | IC FPRF Transceiver LMS7002M; 261 pin aQFN
50 | M24128 | 2 | IC2, IC16 | M24128-DFMC6TG | STMicroelectronics | M24128-DFMC6TG | Digi-Key | 497-15739-1-ND | EEPROM Memory IC 128Kb (16K x 8) I²C 1MHz 450ns 8-UFDFPN (2x3) | NF(IC2 IC16)
51 | CAT24C128WI-GT3 | 2 | IC3, IC18 | SOIC127P600-8DL_v2 | ON Semiconductor | CAT24C128WI-GT3 | Digi-Key | CAT24C128WI-GT3CT-ND | EEPROM Memory IC 128Kb (16K x 8) I²C 1MHz 400ns 8-SOIC
52 | PE42422 | 4 | IC4, IC8, IC10, IC11 | PE42422_QFN12 | Peregrine Semiconductor | PE42422MLAA-Z | Digi-Key | 1046-1062-1-ND | IC RF SWITCH SPDT 50 OHM 12QFN
53 | Duplexer B8 (B5) | 1 | IC5 | SAW_filter_duplexer_TAIYO_YUDEN_1p8x1p4_2p0x1p6 | Taiyo Yuden | D5DA942M5K2S2 | Taiyo Yuden | D5DA942M5K2S2 | RF Diplexor 880MHz ~ 915MHz / 925MHz ~ 960MHz 8-SMD, No Lead | NF(IC5)
54 | SKY13411-374LF | 2 | IC6, IC9 | SKY13411-374LF | Skyworks Solutions Inc. | SKY13411-374LF | Digi-Key | 863-1455-1-ND | RF Switch IC 802.11a/b/g/n DPDT 50 Ohm 6-MLPD (1.5x1.5)
55 | Duplexer B3 (B2) | 1 | IC7 | SAW_filter_duplexer_TAIYO_YUDEN_1p8x1p4_2p0x1p6 | Taiyo Yuden | D6DA1G842K2C4-Z | Taiyo Yuden | D6DA1G842K2C4-Z | SAW DUPLEXER, LTE, BAND 3, 1814 | NF(IC7)
56 | 10M16SAU169C8G | 1 | IC12 | 10M16SAU169C8G | Altera | 10M16SAU169C8G | Digi-Key | 544-3110-ND | IC FPGA/CPLD NV 130 I/O 169UBGA
57 | LM75 | 1 | IC13 | HWSON8_LM75 | NXP Semiconductors | LM75BTP,147 | Digi-Key | 568-9815-2-ND | SENSOR TEMPERATURE I2C 8HWSON
58 | NEO-M8Q | 1 | IC14 | NEO-7M/8M | u-blox | Loading... | Digi-Key | 672-1009-1-ND
59 | 74AHC595 | 4 | IC15, IC17, IC19, IC22 | 74HC595BQ,115 | Nexperia USA Inc. | 74AHC595BQ,115 | Digi-Key | 1727-6021-2-ND | C 8BIT SHIFT REGISTER 16-DHVQFN
60 | ATECC508A | 1 | IC20 | ATECC508A_UDFN8 | Microchip | ATECC508A-MAHDA-S | Digi-Key | ATECC508A-MAHDA-SDKR-ND | Authentication Chip IC Networking and Communications 8-UDFN (2x3)
61 | ATECC508A | 1 | IC21 | SOIC127P600-8DL_v2 | Microchip Technology | ATECC508A-SSHDA-T | Digi-Key | ATECC508A-SSHDA-TCT-ND | Authentication Chip IC Networking and Communications 8-SOIC | NF(IC21)
62 | IS25LQ040 | 1 | IC23 | M25P40-VMN6TPB_SO8N | ISSI, Integrated Silicon Solution Inc | IS25LQ040B-JNLE | Digi-Key | 706-1316-ND | FLASH - NOR Memory IC 4Mb (512K x 8) SPI - Quad I/O 104MHz 8-SOIC
63 | LAN9514-JZX | 1 | IC24 | LAN9514I-JZX_QFN50P900X900X100-65N | Microchip Technology | LAN9514-JZX-TR | Digi-Key | LAN9514-JZX-DKR-ND | Ethernet Bridge, USB to Ethernet USB 2.0, 10/100 Base-T/TX PHY USB Interface 64-QFN (9x9
64 | 93LC66AT | 1 | IC25 | SOIC127P600-8DL_v2 | Microchip Technology | 93LC66AT-I/SN | Digi-Key | 93LC66AT-I/SNDKR-ND | EEPROM Memory IC 4Kb (512 x 8) SPI 2MHz 8-SOIC | NF(IC25)
65 | AP2553 | 2 | IC26, IC33 | SOT23-6 | Diodes | AP2553W6-7 | Digi-Key | AP2553W6-7DIDKR-ND | IC PD SW CURR LIMIT SOT26
66 | FT601Q | 1 | IC27 | FT601Q | FTDI, Future Technology Devices International Ltd | FT601Q-B-T | Digi-Key | 768-1311-ND | IC USB3-32BIT SYNC FIFO 76QFN
67 | FSUSB42UMX | 3 | IC28, IC29, IC31 | FSUSB42UMX | ON Semiconductor | FSUSB42UMX | Digi-Key | FSUSB42UMXCT-ND | USB Switch IC 1 Channel 10-UMLP (1.8x1.4)
68 | WiFi Module WF111 | 1 | IC30 | WF111-A-V1_WIFI | Bluegiga Technologies | WF111-A-V1 | Digi-Key | 1446-1031-6-ND | RF TXRX MODULE WIFI CHIP ANT | NF(IC30)
69 | NC7WZ16P6X | 1 | IC32 | SC-70_NC7WZ16P6X | ON Semiconductor / Fairchild | NC7WZ16P6X | Digi-Key | NC7WZ16P6XDKR-ND | Buffer, Non-Inverting 2 Element 1 Bit per Element Push-Pull Output SC-70-6
70 | LMK00105 | 1 | IC34 | LMK00105SQ | Texas Instruments | LMK00105SQ/NOPB | Digi-Key | LMK00105SQ/NOPBCT-ND | IC CLK BUFFER 2:5 200MHZ 24WQFN
71 | AD5662 | 1 | IC35 | AD5662_SOT23-8 | Analog Devices Inc. | AD5662BRJZ-2REEL7 | Digi-Key | AD5662BRJZ-2REEL7CT-ND | IC DAC 16BIT BUFF V-OUT SOT23-8
72 | ADF4002 | 1 | IC36 | ADF4002 | Analog Devices Inc | ADF4002BCPZ-RL7 | Digi-Key | ADF4002BCPZ-RL7CT-ND | IC PLL FREQUENCY SYNTH 20-LFCSP
73 | AD5601BKSZ-REEL7 | 1 | IC37 | AD5601_SOT23-6 | Analog Devices | AD5601BKSZ-REEL7 | Digi-Key | AD5601BKSZ-REEL7TR-ND | IC DAC 8BIT BUFF V-OUT SC70-6 | NF(IC37)
74 | TPS23753APWR | 1 | IC38 | TPS23753APWR _TSSOP14 | Texas Instruments | TPS23753APWR | Digi-Key | 296-39365-1-ND | Power Over Ethernet Controller 1 Channel 802.3at (PoE+), 802.3af (PoE) 14-TSSOP
75 | LMZ10501 | 4 | IC39, IC40, IC45, IC46 | LMZ10501 | Texas Instruments | LMZ10501SILR | Digi-Key | 296-37104-1-ND | n Non-Isolated PoL Module DC DC Converter 1 Output 0.6 ~ 3.6 V 1A 2.7V - 5.5V Input
76 | AP7361-FGE | 4 | IC41, IC42, IC43, IC44 | AP7361 | Diodes Incorporated | AP7361-FGE-7 | Digi-Key | AP7361-FGE-7DICT-ND | IC REG LDO ADJ 1A 8DFN | NF(IC41)
77 | SMA board edge | 6 | J1, J2, J7, J20, J24, J25 | SMA_connector_board_edge_SM | RF Solutions | CON-SMA-EDGE-S | Digi-Key | CON-SMA-EDGE-S-ND | SMA Connector Jack, Female Socket Board Edge, End Launch Solder | NF(J20)
78 | FPGA JTAG (board edge) | 1 | J3 | Header7x1_TH | Sullins Connector Solutions | PEC07SAAN | Digi-Key | S1012E-07-ND | 7 Positions Header, Unshrouded, Breakaway Connector 0.100" (2.54mm) Through Hole Tin | NF(J3)
79 | FPGA JTAG | 1 | J4 | SWD_10_pin | Harwin Inc | M50-3600542 | Digi-Key | 952-1389-ND | CONN HDR 1.27MM SMD AU 10POS
80 | FPGA GPIO | 1 | J5 | SWD_10_pin | Harwin Inc | M50-3600542 | Digi-Key | 952-1389-ND | CONN HDR 1.27MM SMD AU 10POS
81 | Batt | 1 | J6 | HDR_1x2 | 3M | 961102-6404-AR | Digi-Key | 3M9447-ND | 2 Positions Header, Unshrouded Connector 0.100" (2.54mm) Through Hole Gold | NF(J6)
82 | FAN | 1 | J8 | HDR_1x2 | 3M | 961102-6404-AR | Digi-Key | 3M9447-ND | 2 Positions Header, Unshrouded Connector 0.100" (2.54mm) Through Hole Gold
83 | SI-52003-F | 1 | J9 | RJ45_SI-52003-F | Stewart Connector | SI-52003-F | Digi-Key | 380-1119-ND | 1 Port RJ45 Magjack Connector Through Hole 10/100 Base-T, AutoMDIX, Power over Ethernet (PoE)
84 | 2xUSB A | 1 | J10 | USB_typeA_double_USBR-A-D-F-O-TH | Samtec | USBR-A-D-F-O-TH | Digi-Key | SAM10376-ND | USB - A USB 2.0 Receptacle Connector 8 Position Through Hole, Right Angle
85 | USB | 2 | J11, J12 | HEADER4X1_TH | Wurth Electronics Inc. | 61300411121 | Digi-Key | 732-5317-ND | 4 Positions Header Connector 0.100" (2.54mm) Through Hole Gold | NF(J11 J12)
86 | DDR2 (1.8V) SODIMM SOCKET | 1 | J13 | TE_1717254-1_DDR_SODIMM | TE Connectivity AMP Connectors | 1717254-4 | Digi-Key | A130932CT-ND | 200 Position SODIMM DDR SDRAM Socket Surface Mount, Right Angle
87 | USB Boot | 1 | J14 | HDR_1x2 | 3M | 961102-6404-AR | Digi-Key | 3M9447-ND | 2 Positions Header, Unshrouded Connector 0.100" (2.54mm) Through Hole Gold
88 | USB Micro Type B | 1 | J15 | microUSB_v2 | Amphenol FCI | 10118193-0001LF | Digi-Key | 609-4616-2-ND | CONN USB MICRO B RECPT SMT R/A
89 | Micro SD card holder | 1 | J16 | MICRO_SD_CARD_114-00841-68_v2 | Amphenol Commercial Products | 114-00841-68 | Digi-Key | 114-00841-68-1-ND | 10 (8 + 2) Position Card Connector Secure Digital - microSD™ Surface Mount, Right Angle Gold
90 | UART | 1 | J17 | HEADER4X1_TH | Wurth Electronics Inc. | 61300411121 | Digi-Key | 732-5317-ND | 4 Positions Header Connector 0.100" (2.54mm) Through Hole Gold
91 | EXT_USB | 1 | J18 | HDR_1x2 | 3M | 961102-6404-AR | Digi-Key | 3M9447-ND | 2 Positions Header, Unshrouded Connector 0.100" (2.54mm) Through Hole Gold
92 | HDMI | 1 | J19 | HDMI_AMPHENOL_10029449-111RLF | Amphenol FCI | 10029449-111RLF | Mouser | 649-10029449-111RLF | HDMI HDMI™ 1.4 Receptacle Connector 19 Position Surface Mount, Right Angle; Through Hole
93 | A/V, 3.5mm | 1 | J21 | Audio_jack_3.5mm | CUI Inc. | SJ-43515TS | Digi-Key | CP-43515TS-ND | CONN JACK 4COND 3.5MM R/A
94 | FPC 15-pin | 2 | J22, J23 | FPC_CONNECTOR_15pin_1-1734248-5 | TE Connectivity | 1-1734248-5 | Digi-Key | A101418DKR-ND | 15 Position FPC Connector Contacts, Vertical, 1 Sided 0.039" (1.00mm) Surface Mount
95 |  | 1 | J26 | HDR_1x2 | 3M | 961102-6404-AR | Digi-Key | 3M9447-ND | 2 Positions Header, Unshrouded Connector 0.100" (2.54mm) Through Hole Gold
96 | Header 3X2 | 1 | J27 | Header3x2 | Harwin | M20-9980346 | Digi-Key | 952-2121-ND | Connector Header Through Hole 6 position 0.100" (2.54mm)
97 | CONN_PWR_JACK_2.1x5.5mm | 1 | J28 | CONN_PWR_JACK_v2 | CUI | PJ-002A | Digi-Key | CP-002A-ND | Power Barrel Connector Jack 2.10mm ID (0.083"), 5.50mm OD (0.217") Through Hole, Right Angle
98 | 1 pcs. | 3 | JMP1, JMP2, JMP3 |  | Sullins | SPC02SYAN | Digi-Key | S9001-ND | 2 (1 x 2) Position Shunt Connector Black Closed Top 0.100" (2.54mm) Gold | NF(JMP2)
99 | 47nH | 1 | L1 | RES0402 | COILCRAFT | 0402HP-47NXJLU | Farnell | 2285856 | COILCRAFT 0402HP-47NXJLU Surface Mount High Frequency Inductor, 0402HP Series, 47 nH, 420 mA, 0402 [1005 Metric], Wirewound
100 | 10uH, 1.2A | 1 | L2 | NRS4018T3R3MDGJ_inductor | Taiyo Yuden | NRS4018T100MDGJ | Digi-Key | 587-2886-1-ND | FIXED IND 10UH 1.2A 180 MOHM SMD
101 | 3.3uH, 2.2A | 1 | L3 | NRS4018T3R3MDGJ_inductor | Bourns | SRN4018-3R3M | Digi-Key | SRN4018-3R3MCT-ND | 3.3µH Semi-Shielded Wirewound Inductor 2.2A 66 mOhm Max Nonstandard
102 | LED_RG_SMD | 6 | LED1, LED2, LED3, LED4, LED5, LED6 | LED-2x0603 | Avago Technologies US Inc. | HSMF-C165 | Digi-Key | 516-1419-1-ND | LED GREEN/RED DIFFUSED 0603 SMD
103 | WST-1203UX | 1 | LS1 | BUZZER_WST-1203UX | Soberton Inc. | WST-1203UX | Digi-Key | 433-1047-ND | Buzzers Indicator, Internally Driven Magnetic 3V 30mA 2.3kHz 82dB @ 3V, 10cm Through Hole PC Pins
104 | BMI-S-230-C | 2 | MECH1, MECH3 |  | Laird Technologies EMI | BMI-S-230-C | Digi-Key | 903-1471-ND | RF Shield Cover 2.000" (50.80mm) X 1.500" (38.10mm) Vent Holes in Pattern Snap Fit
105 | BMI-S-230-F-R | 2 | MECH2, MECH4 | RFI_SHIELD_BMI-S-230-F-R | Laird Technologies EMI | BMI-S-230-F-R | Digi-Key | 903-1470-1-ND | RF Shield Frame 2.000" (50.80mm) X 1.500" (38.10mm) Solder
106 | # pcs. | 4 | MECH5, MECH6, MECH7, MECH8 | PCB_standoff | FIX&FASTEN | FIX-MAE-5TV | TME | FIX-MAE-5TV | PCB distance; polyamide; L:5mm; Colour: natural; Øcutout:3mm
107 | 8.2nH, 5% | 5 | MN1, MN2, MN4, MN5, MN22 | RES0402 | COILCRAFT | 0402HP-8N2XJLU | Farnell | 2285826 | Surface Mount High Frequency Inductor, 0402HP Series, 8.2 nH, ± 5%, 0402 [1005 Metric], 5.4 GHz | NF(MN4 MN5 MN22)
108 | 0.8pF | 2 | MN3, MN9 | CAP0402 | Murata Electronics North America | GRM1555C1HR80BA01D | Digi-Key | 490-6269-1-ND | 0.80pF ±0.1pF 50V C0G, NP0 Ceramic Capacitor -55°C ~ 125°C Surface Mount, MLCC 0402 (1005 Metric) 0.039" L x 0.020" W (1.00mm x 0.50mm)
109 | 1pF | 3 | MN6, MN18, MN27 | CAP0402 | TDK Corporation | C1005C0G1H010B050BA | Digi-Key | 445-4854-6-ND | 1pF ±0.1pF 50V C0G, NP0 Ceramic Capacitor -55°C ~ 125°C Surface Mount, MLCC 0402 (1005 Metric) 0.039" L x 0.020" W (1.00mm x 0.50mm) | NF(MN6 MN18)
110 | 0.5pF | 2 | MN7, MN26 | CAP0402 | Yageo | CC0402CRNPO9BNR50 | Digi-Key | 311-1001-1-ND | 0.50pF ±0.25pF 50V C0G, NP0 Ceramic Capacitor -55°C ~ 125°C Surface Mount, MLCC 0402 (1005 Metric) 0.039" L x 0.020" W (1.00mm x 0.50mm) | NF(MN26)
111 | 22nH, 5% | 1 | MN8 | RES0402 | Murata Electronics North America | LQW15AN22NJ00D | Digi-Key | 490-1150-1-ND | 22nH Unshielded Wirewound Inductor 310mA 300 mOhm Max 0402 (1005 Metric) | NF(MN8)
112 | 100uH | 2 | MN10, MN11 | RES0805 | TDK Corporation | MLF2012C101KT000 | Digi-Key | 445-1071-1-ND | FIXED IND 100UH 2MA 3.1 OHM SMD
113 | 4.3nH, 5% | 1 | MN12 | RES0402 | TDK Corporation | MLG1005S4N3STD25 | Digi-Key | 445-16307-1-ND | 4.3nH Unshielded Multilayer Inductor 700mA 200 mOhm Max 0402 (1005 Metric) | NF(MN12)
114 | 0R | 65 | MN13, MN14, R15, R16, R17, R18, R19, R22, R23, R32, R33, R34, R35, R36, R37, R44, R46, R47, R49, R52, R53, R54, R55, R56, R57, R59, R61, R63, R71, R80, R92, R95, R96, R97, R102, R109, R114, R121, R122, R123, R126, R128, R129, R130, R132, R134, R143, R148, R149, R161, R163, R164, R167, R170, R172, R173, R176, R180, R184, R203, R209, R229, R230, R238, R240 | RES0402 | Yageo | RC0402JR-070RL | Digi-Key | 311-0.0JRTR-ND | RES SMD 0.0OHM JUMPER 1/16W 0402 | NF(R22 R33 R34 R47 R49 R52 R53 R55 R57 R59 R63 R71 R92 R96 R97 R114 R121 R122 R126 R128 R129 R132 R143 R148 R149 R170 R172 R173 R240)
115 | 12nH, 5% | 1 | MN16 | RES0402 | Murata Electronics North America | LQG15HS12NJ02D | Digi-Key | 490-2624-1-ND | 12nH Unshielded Multilayer Inductor 500mA 280 mOhm Max 0402 (1005 Metric) | NF(MN16)
116 | 10nH, 5% | 1 | MN17 | RES0402 | Murata Electronics North America | LQG15HS10NJ02D | Digi-Key | 490-2623-1-ND | 10nH Unshielded Multilayer Inductor 500mA 260 mOhm Max 0402 (1005 Metric) | NF(MN17)
117 | 2pF | 3 | MN19, MN25, MN28 | CAP0402 | AVX | 04025U2R0BAT2A | Farnell | 2332536 | SMD Multilayer Ceramic Capacitor, U Series, 2 pF, ± 0.1pF, C0G / NP0, 50 V, 0402 [1005 Metric]
118 | 510pF | 2 | MN21, MN24 | CAP0402 | Murata Electronics North America | GRM1555C1H511JA01D | Digi-Key | 490-3237-1-ND | 510pF ±5% 50V C0G, NP0 Ceramic Capacitor -55°C ~ 125°C Surface Mount, MLCC 0402 (1005 Metric) 0.039" L x 0.020" W (1.00mm x 0.50mm)
119 | 1.2pF | 1 | MN23 | CAP0402 | Murata Electronics North America | GRM1555C1H1R2CA01D | Digi-Key | 490-5927-1-ND | '1.2pF ±0.25pF 50V C0G, NP0 Ceramic Capacitor -55°C ~ 125°C Surface Mount, MLCC 0402 (1005 Metric) 0.039" L x 0.020" W (1.00mm x 0.50mm)
120 | Raspberry Pi Compute Module 3+ (8GB eMMC) | 1 | PC1 |  | RASPBERRY-PI | CM3+/8GB | Farnell | 2989462 | Single Board Computer, Raspberry Pi Compute Module 3 +, BCM2837B0 SoC, 8GB eMMC Memory
121 | 10k, 1% | 38 | R1, R2, R3, R4, R5, R10, R11, R26, R27, R28, R29, R30, R38, R39, R40, R41, R42, R43, R51, R69, R75, R76, R78, R85, R88, R90, R91, R99, R104, R105, R106, R159, R187, R188, R189, R195, R207, R212 | RES0402 | Yageo | RC0402FR-0710KL | Digi-Key | 311-10.0KLRTR-ND | RES SMD 10K OHM 1% 1/16W 0402 | NF(R27 R104 R195)
122 | 49.9R, 1% | 18 | R6, R7, R8, R9, R79, R82, R83, R84, R144, R165, R177, R183, R191, R192, R193, R196, R197, R198 | RES0402 | Samsung Electro-Mechanics America, Inc. | RC1005F49R9CS | Digi-Key | 1276-3469-6-ND | RES SMD 49.9 OHM 1% 1/16W 0402 | NF(R144)
123 | 2k2, 1% | 4 | R12, R13, R154, R156 | RES0402 | Stackpole Electronics Inc | RMCF0402FT2K20 | Digi-Key | RMCF0402FT2K20CT-ND | RES SMD 2.2K OHM 1% 1/16W 0402
124 | 0R | 1 | R14 | RES0201 | Rohm Semiconductor | RC0201FR-070RL | Digi-Key | 311-0.0MCT-ND | RES SMD 0.0OHM JUMPER 1/20W 0201
125 | 10R | 4 | R20, R21, R24, R25 | RES0201 | Panasonic Electronic Components | ERJ-1GEF10R0C | Digi-Key | P10.0ABCT-ND | RES SMD 10 OHM 1% 1/20W 0201
126 | 1k, 1% | 12 | R31, R73, R113, R146, R147, R179, R181, R186, R217, R219, R224, R232 | RES0402 | Stackpole Electronics Inc | RMCF0402FT1K00 | Digi-Key | RMCF0402FT1K00TR-ND | RES SMD 1K OHM 1% 1/16W 0402 | NF(R146 R147 R186 R219)
127 | 3k, 1% | 6 | R45, R48, R127, R133, R185, R194 | RES0402 | Vishay Dale | CRCW04023K00FKED | Digi-Key | 541-3.00KLCT-ND | RES SMD 3K OHM 1% 1/16W 0402 | NF(R194)
128 | 10R, 5% | 3 | R50, R81, R178 | RES0402 | Yageo | RC0402JR-0710RL | Digi-Key | 311-10JRTR-ND | RES SMD 10 OHM 5% 1/16W 0402
129 | 100R, 1% | 14 | R58, R60, R62, R64, R65, R66, R67, R68, R70, R72, R87, R89, R153, R155 | RES0402 | Stackpole Electronics Inc. | RMCF0402FT100R | Digi-Key | RMCF0402FT100RDKR-ND | RES SMD 100 OHM 1% 1/16W 0402
130 | 249R, 1% | 3 | R74, R152, R157 | RES0402 | Stackpole Electronics Inc | RMCF0402FT249R | Digi-Key | RMCF0402FT249RCT-ND | RES SMD 249 OHM 1% 1/16W 0402
131 | 1M, 1% | 1 | R86 | RES0402 | Yageo | RC0402FR-071ML | Digi-Key | 311-1.00MLRCT-ND | 1 MOhms ±1% 0.063W, 1/16W Chip Resistor 0402 (1005 Metric) Moisture Resistant Thick Film
132 | 12k, 1% | 1 | R93 | RES0402 | Samsung Electro-Mechanics | RC1005F123CS | Digi-Key | 1276-4122-1-ND | 12 kOhms ±1% 0.063W, 1/16W Chip Resistor 0402 (1005 Metric) Moisture Resistant Thick Film
133 | 12.4k, 1% | 1 | R94 | RES0402 | Yageo | RT0402BRE0712K4L | Digi-Key | YAG4337CT-ND | 12.4 kOhms ±0.1% 0.063W, 1/16W Chip Resistor 0402 (1005 Metric) Thin Film
134 | 0R | 8 | R98, R158, R162, R166, R168, R169, R171, R174 | RES0402_v2 | Yageo | RC0402JR-070RL | Digi-Key | 311-0.0JRTR-ND | RES SMD 0.0OHM JUMPER 1/16W 0402 | NF(R98 R158 R166 R168 R169 R171 R174)
135 | 44.2k, 1% | 4 | R100, R101, R160, R208 | RES0402 | Panasonic Electronic Components | ERJ-2RKF4422X | Digi-Key | P44.2KLCT-ND | RES SMD 44.2K OHM 1% 1/10W 0402 | NF(R101)
136 | 4K7, 1% | 1 | R103 | RES0402 | Yageo | RC0402FR-074K7L | Digi-Key | 311-4.7KLRCT-ND | ±1% 0.063W, 1/16W Chip Resistor 0402 (1005 Metric) Moisture Resistant Thick Film | NF(R103)
137 | 1k6, 1% | 1 | R108 | RES0402 | Yageo | RC0402FR-071K6L | Digi-Key | YAG3045CT-ND | RES SMD 1.6K OHM 1% 1/16W 0402
138 | 100k, 1% | 10 | R110, R111, R115, R116, R124, R125, R131, R145, R150, R151 | RES0402 | Vishay Dale | ERJ-2GEJ104X | Digi-Key | 541-3960-1-ND | RES SMD 100K OHM 1% 1/10W 0402
139 | 22R | 10 | R77, R107, R112, R135, R136, R137, R139, R140, R142, R175 | RES0402 | Yageo | RC0402FR-0722RL | Digi-Key | 311-22.0LRTR-ND | RES SMD 22 OHM 1% 1/16W 0402 | NF(R175)
140 | 0R | 7 | R117, R118, R119, R120, R235, R239, R241 | RES0805 | Vishay Dale | CRCW08050000Z0EA | Digi-Key | 541-0.0ATR-ND | RES SMD 0.0 OHM JUMPER 1/8W 0805 | NF(R119 R235 R239 R241)
141 | 47.5k, 1% | 1 | R138 | RES0402 | Yageo | RC0402FR-0747K5L | Digi-Key | 311-47.5KLRCT-ND | RES SMD 47.5K OHM 1% 1/16W 0402
142 | 1M | 1 | R141 | RES0402 | TE CONNECTIVITY | CRG0402F1M0 | Farnell | 2331481 | RES SMD 1M OHM 1% 1/16W 0402
143 | 470R, 0.5% | 2 | R182, R223 | RES0402 | Panasonic Electronic Components | ERA-2AED471X | Digi-Key | P470DETR-ND | RES SMD 470 OHM 0.5% 1/16W 0402 | NF(R223)
144 | 330R, 5% | 1 | R190 | RES0402 | Yageo | RC0402JR-07330RL | Digi-Key | 311-330JRTR-ND | RES SMD 330 OHM 5% 1/16W 0402
145 | 10R, 1% | 2 | R199, R216 | RES0603 | Vishay | CRCW060310R0FKEAC | Digi-Key | 541-3952-1-ND | 10 Ohms ±1% 0.1W, 1/10W Chip Resistor 0603 (1608 Metric) Thick Film
146 | 39k, 1% | 1 | R200 | RES0805 | Yageo | RC0805FR-0739KL | Digi-Key | 311-39.0KCRCT-ND | 39 kOhms ±1% 0.125W, 1/8W Chip Resistor 0805 (2012 Metric) Moisture Resistant Thick Film
147 | 10R, 1% | 1 | R201 | RES0805 | Vishay | CRCW080510R0FKEAC | Digi-Key | 541-4132-1-ND | 10 Ohms ±1% 0.125W, 1/8W Chip Resistor 0805 (2012 Metric) Thick Film
148 | 24.9k, 1% | 1 | R202 | RES0402 | Yageo | RC0402FR-0724K9L | Digi-Key | 311-24.9KLRCT-ND | 24.9 kOhms ±1% 0.063W, 1/16W Chip Resistor 0402 (1005 Metric) Moisture Resistant Thick Film
149 | 90.9R. 1% | 1 | R204 | RES0603 | Yageo | RC0603FR-0790R9L | Digi-Key | 311-90.9HRCT-ND | 90.9 Ohms ±1% 0.1W, 1/10W Chip Resistor 0603 (1608 Metric) Moisture Resistant Thick Film
150 | 20R 1% | 1 | R205 | RES0805 | Yageo | RC0805FR-0720RL | Digi-Key | 311-20.0CRCT-ND | 20 Ohms ±1% 0.125W, 1/8W Chip Resistor 0805 (2012 Metric) Moisture Resistant Thick Film
151 | 680R, 1% | 2 | R206, R215 | RES0402 | Yageo | RC0402FR-07680RL | Digi-Key | 311-680LRCT-ND | 680 Ohms ±1% 0.063W, 1/16W Chip Resistor 0402 (1005 Metric) Moisture Resistant Thick Film
152 | 80.6k, 1% | 1 | R210 | RES0402 | Yageo | RC0402FR-0780K6L | Digi-Key | 311-80.6KLRCT-ND | 80.6 kOhms ±1% 0.063W, 1/16W Chip Resistor 0402 (1005 Metric) Moisture Resistant Thick Film
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

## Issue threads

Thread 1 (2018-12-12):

USB connecor TVS/ESD protection / EMI filters?

laf0rge, 2018-12-12:
I briefly reviewed the LimeNET micro schematics and I couldn't find any TVS/ESD protection devices for the external USB sockets.  I would consider those quite mandatory in any USB device - like for any external connector which the User can touch and where ESD can enter the board.

Less mandatory, but typically a good idea particularly in RF devices, I couldn't find they typical USB emi filter / common-mode chokes that prevent noise from external USB devices (host/peripheral) to enter the board (and possibly degrade receiver performance) - and which also attenuate any conducted emissions the board may attenuate.

Of course those are just my thoughts, maybe your requirements differ or I overlooked something in the schematics.  So this is not a bug report, just a comment / feedback.

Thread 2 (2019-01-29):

Question: PTP V2.0

spa49, 2019-01-29:
Hi,
is the Ethernet Controler capable of providing Hardware PTP (Precision Time Protocol)?

thank you...

9600, 2019-01-29:
The same LAN9514 IC is used as with the main Raspberry Pi boards, so I'm afraid not.

Closed 2019-01-29.

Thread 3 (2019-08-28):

GNSS module not connected to either UART nor USB of ARM

laf0rge, 2019-08-28:
As far as I'm reading the schematics (also confirmed by my experiments), the GNSS module seems only connected to the FPGA by default.  As for the UART, I can understand that that to some extent, as the softcore in the FPGA might want to communicate with the GNSS chip to understand whether or not the receiver has a fix, etc.

But for the USB, I'm a bit puzzled.  Both R96 and R97 are marked as "NF" (not fit), and indeed they are not placed on the board.  Why leave it to the user to solder those 0402 resistors if he wants to run software on the host that interacts with the GNSS module?

BTS monitoring software typically also wants to know at the very least the lock status of the receiver.  It also might want to know the geographic position of the device to assist in netwokr planning.  Particularly for small cells or even femtocells the position is not known a-priori like in a macro site where you first are building an antenna tower and should know where it's actually located.

vbuitvydas, 2019-08-29:
UART of GNSS is connected to FPGA and GNSS_UART_TX line is connected to Raspberry Pi by default. Check   [3.8 Communication interfaces (I2C, UART, SPI)](https://wiki.myriadrf.org/LimeNET-Micro_v2.1_hardware_description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). Raspberry Pi can receive status from GNSS through UART. Also in current gateware FPGA can receive fix and location status and store it to internal registers which are also accessible from host (GNSS-> FPGA -> FTDI -> HOST).

So already there is an option for host to access status from GNSS and for this reason R96,R97 are left NF, this gives other option to connect some external USB device to J11 connector.

Closed 2019-09-03.

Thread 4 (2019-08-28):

Is the barrel connector for 5V DC or 12V DC?

laf0rge, 2019-08-28:
The README file at https://github.com/myriadrf/LimeNET-Micro/blob/master/README.md states "12V DC barrel connector" while the board silk-screen of a 2v1 board clearly reads "5V DC" next to the connector.

Please fix accordingly. There might be other places to fix like the wiki, I didn't check that part.

laf0rge, 2019-08-28:
https://myriadrf.org/projects/integrated/limenet-micro/ also states 12V

laf0rge, 2019-08-28:
https://wiki.myriadrf.org/LimeNET_Micro states 5V

laf0rge, 2019-08-28:
https://wiki.myriadrf.org/LimeNET-Micro_v2.1_hardware_description also states 5V

vbuitvydas, 2019-09-03:
> The README file at https://github.com/myriadrf/LimeNET-Micro/blob/master/README.md states "12V DC barrel connector" while the board silk-screen of a 2v1 board clearly reads "5V DC" next to the connector.
>
> Please fix accordingly. There might be other places to fix like the wiki, I didn't check that part.

Fixed;

> https://wiki.myriadrf.org/LimeNET_Micro states 5V

Correct statement;

> https://wiki.myriadrf.org/LimeNET-Micro_v2.1_hardware_description also states 5V

Correct statement;

Closed 2019-09-03.

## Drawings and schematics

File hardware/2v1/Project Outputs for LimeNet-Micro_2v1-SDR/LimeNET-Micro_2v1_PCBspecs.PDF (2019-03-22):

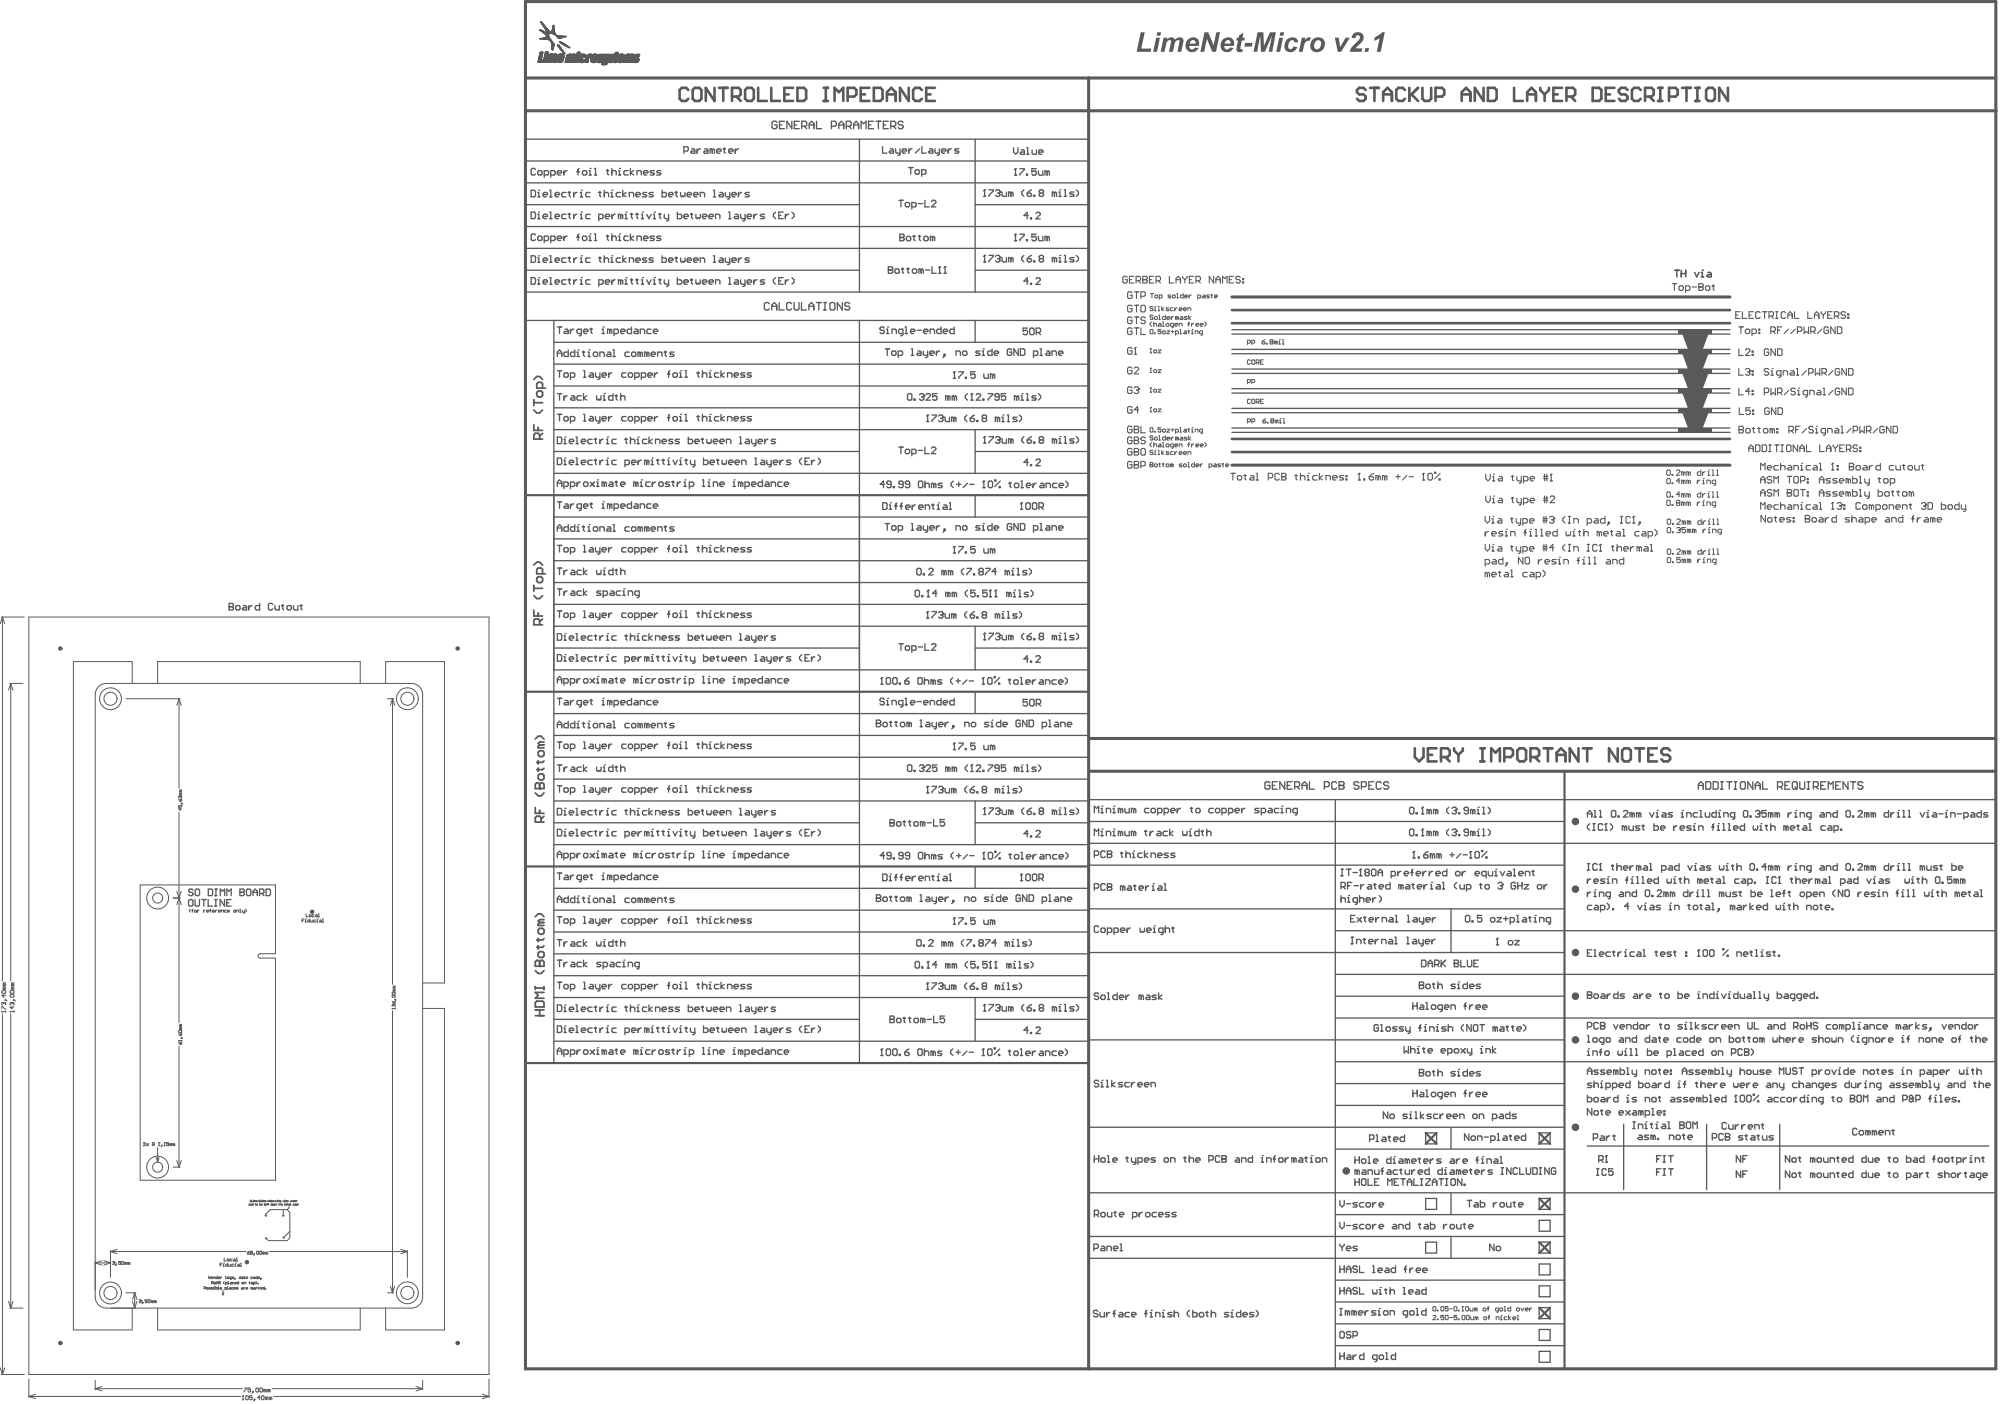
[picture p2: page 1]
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

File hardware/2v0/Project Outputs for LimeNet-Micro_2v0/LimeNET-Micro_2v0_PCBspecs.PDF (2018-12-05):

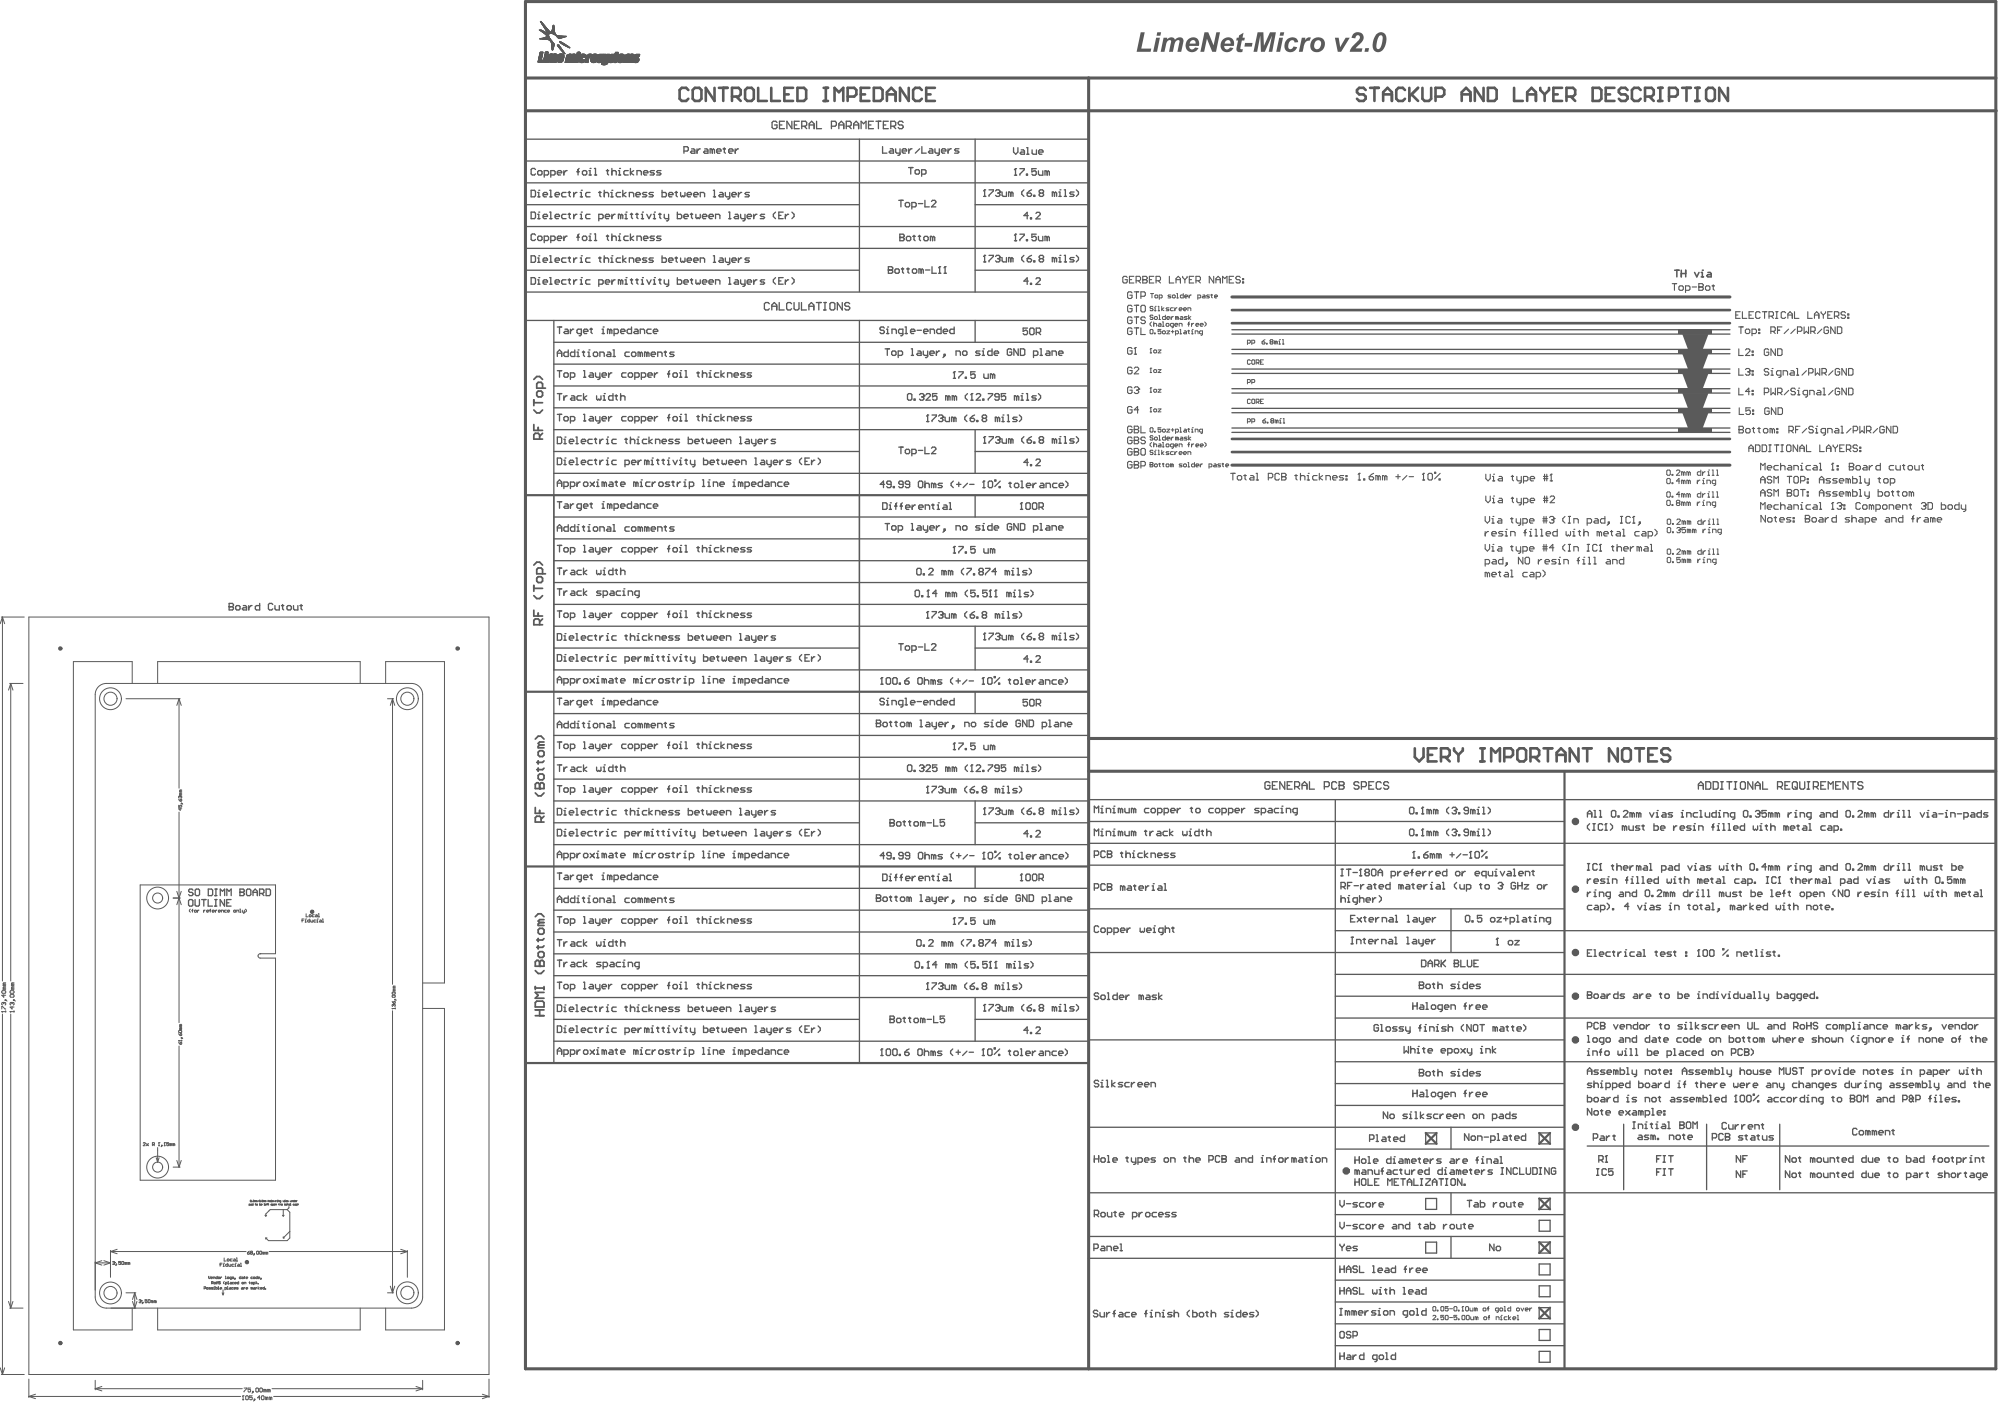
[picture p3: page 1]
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

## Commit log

2018-12-05 Initial commit.
    [01_BlockDiagram.SchDoc, 02_PowerDiagram.SchDoc, 03_ClockDiagram.SchDoc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]
2019-03-22 Version 2.1 Altium project added.
    [01_BlockDiagram.SchDoc, 02_PowerDiagram.SchDoc, 03_ClockDiagram.SchDoc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]
2019-08-29 Fixed incorrect DC barrel connector voltage in README file, #4
